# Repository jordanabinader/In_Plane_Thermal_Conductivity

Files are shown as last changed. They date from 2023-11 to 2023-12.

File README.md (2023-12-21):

# In-Plane Thermal Conductivity Project

## Table of Contents
- [In-Plane Thermal Conductivity Project](#in-plane-thermal-conductivity-project)
  - [Table of Contents](#table-of-contents)
  - [Description](#description)
  - [Project Structure](#project-structure)
  - [Using the Repository](#using-the-repository)
    - [Installation](#installation)
    - [Running the program](#running-the-program)
    - [Exiting the program](#exiting-the-program)
  - [Database Schema](#database-schema)
  - [TC08 Note](#tc08-note)

## Description
This project integrates various components such as server, database, web application, controls, and computations for in-plane thermal conductivity analysis. It utilizes a robust Node.js server and a responsive front-end built with Next.js alongside several python scripts communicating with the hardware.

## Project Structure
- **Client**: Implements the user interface using Next.js and manages HTTP requests with axios.
- **Server**: A Node.js server employing Express.js for HTTP requests and connecting to an SQLite3 database, with database manipulation facilitated by Knex.
- **Control**: A collection of python scripts dedicated to recording the data from the thermocouples, controlling the heaters, and calculating the thermal conductivity
  - *Thermal Control*
    - Pico_Talker.py: Setting the duty cycle of the heaters based on the control mode set by the user in the website.
  - *Thermocouple*
    - writeFromDAQ.py: Recieves the data from the TC-08 DAQ and writes the temperatures to the temperature table in the database
    - graphLive.py: Plots the live temperature data along side calculated sin fit for active tests.
    - graphFull.py: Similar functionality to graphLive.py but for looking at the data of previous tests. 

## Using the Repository

### Installation

1. Update and upgrade ubuntu packages
  ```
  sudo apt update && sudo apt upgrade
  ```
2. Install picosdk and drivers for the Pico Logger TC-08. Instructions from: https://www.picotech.com/downloads/linux
  ```
  sudo bash -c 'wget -O- https://labs.picotech.com/Release.gpg.key | gpg --dearmor > /usr/share/keyrings/picotech-archive-keyring.gpg'
  sudo bash -c 'echo "deb [signed-by=/usr/share/keyrings/picotech-archive-keyring.gpg] https://labs.picotech.com/picoscope7/debian/ picoscope main" >/etc/apt/sources.list.d/picoscope7.list'
  sudo apt-get update
  sudo apt-get install libusbtc08
  ```

3. Install Python 3.11
  ```
  sudo apt install python3.11
  ```
4. Install pip
  ```
  sudo apt install python3-pip
  ```

5. Install venv pip package
  ```
  python3.11 -m pip install venv
  ```
6. Install curl
  ```
  sudo apt install curl
  ```
7. Install nvm  
  ```
  curl -o- https://raw.githubusercontent.com/nvm-sh/nvm/v0.39.6/install.sh | bash
  source ~/.bashrc
  ```
8. Install Node LTS 20.10.0 and specify it as default
  ```
  nvm install 20.10.0
  nvm alias default 20.10.0
  ```

9. **Clone the repository**: <!-- Replace git clone command with one specifying version once its released -->
  ```
  git clone https://github.com/jordanabinader/In_Plane_Thermal_Conductivity.git
  cd In_Plane_Thermal_Conductivity/
  ```
10. **Setup the python virtual environment**
  ```
  python3.11 -m venv iptc_venv
  ```
  
11. **Install node dependencies**:
   - For the client:
       ```
       cd client
       npm install
       cd ../
       ```
   - For the server:
       ```
       cd server
       npm install
       cd ../
       ```
12. **Install python dependencies**
  ```
  source iptc_venv/bin/activate
  python3.11 -m pip install -r requirements.txt
  ```

### Running the program
Your current working directory should be the base folder of the In_Plane_Thermal_Conductivity repository

1. Activate the virtual environment
  ```
  source iptc_venv/bin/activate
  ```
2. Check the serial port
  ```
  ls -l /dev/serial/by-id
  ```
  The raspberry pi pico likely defaults to ttyACM0, but if not change the ttyACM0 in the command below to what this command highlights

3. Start everything up
  ```
  python3.11 Startup.py --serial-port /dev/ttyACM0
  ```

### Exiting the program
1. In the terminal window running Startup.py from the command above, hit `ctrl+c`
  
   - A normal exit will look similar to below
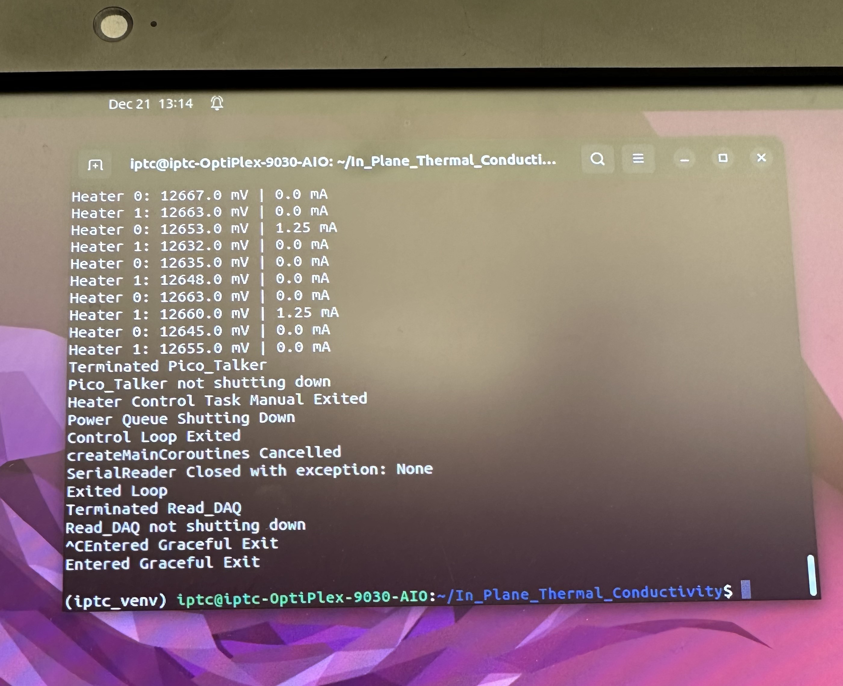
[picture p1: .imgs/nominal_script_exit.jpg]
Image of a nominal exit of the python script

   - If you see more than 3 or 4 print statments in a row that say `{SOMETHING} not shutting down`  the heater control board should be unplugged from and the computer restarted as this means that something went wrong in the shutdown process and the heaters can cause damage if left running while powered

It is also worthwhile to check the terminal output after ending a test to ensure that the heaters get turned off the the thermocouple DAQ gets deactivated properly. The terminal output at the end of a test should look something like the image below. Similar to the what happens when the whole system gets shutdown: If you see more than 3 or 4 print statments in a row that say `{SOMETHING} not shutting down`  the heater control board should be unplugged from and the computer restarted as this means that something went wrong in the shutdown process and the heaters can cause damage if left running while powered. 
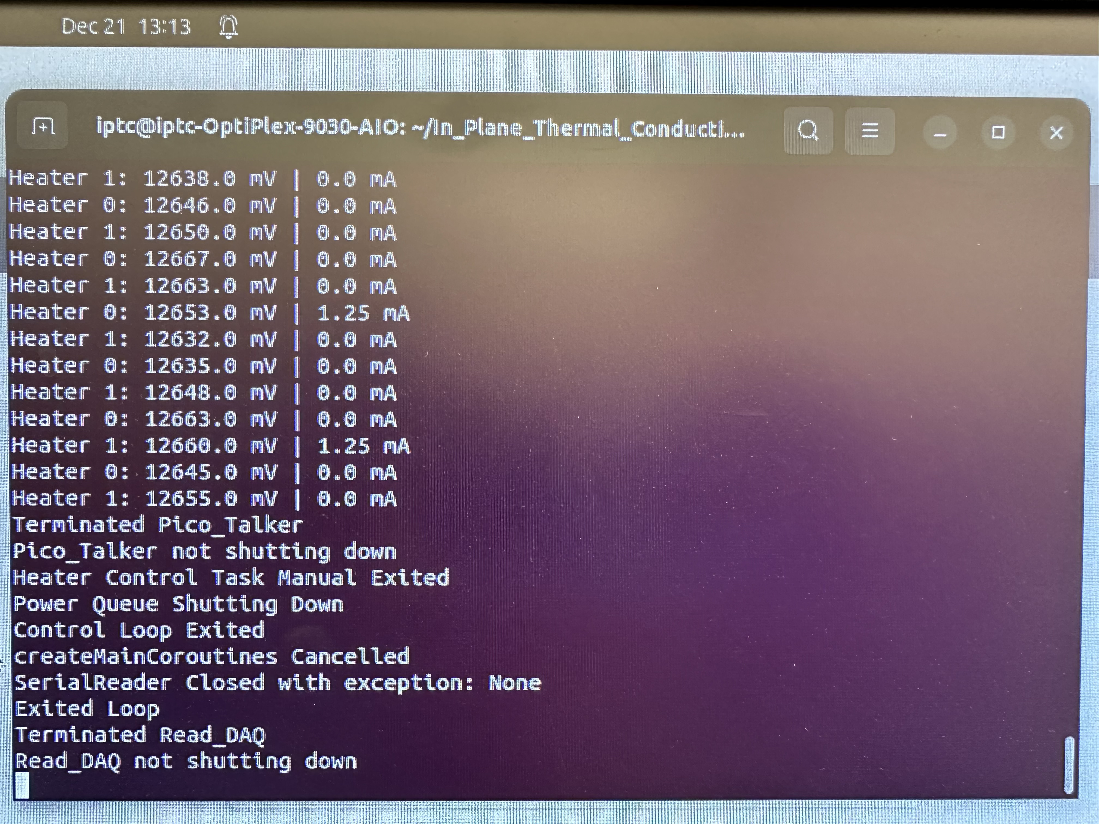
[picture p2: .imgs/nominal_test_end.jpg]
Image of the terminal output when a test is ended properly


## Database Schema
The application uses the following SQLite3 database schemas:

- **Test Settings Table** (`testSettingTableName`):
  - `controlMode`: Float
  - `frequency`: Float
  - `amplitude`: Float
  - `datetime`: DateTime

- **Power Table** (`powerTableName`):
  - `heaterNum`: Float
  - `mV`: Float
  - `mA`: Float
  - `dutyCycle`: Float
  - `datetime`: DateTime

- **Temperature Table** (`temperatureTableName`):
  - `datetime`: DateTime (Default to current time)
  - `relTime`: Float
  - `temp1` to `temp8`: Float (temperature readings for 8 different points)

## TC08 Note
For use with TC-08, you may have to modify library.py of picosdk so it can manually find the installed library

ex. "/Library/Frameworks/Python.framework/Versions/3.12/lib/python3.12/site-packages/picosdk/library.py"

Edit the first line after def _load(self):

library_path = find_library(self.name) ->
library_path = '/Library/Frameworks/PicoSDK.framework/Libraries/libusbtc08/libusbtc08.dylib' For running on Charlie's Macbook Pro

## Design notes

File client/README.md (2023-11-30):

<<<<<<< HEAD
# Capstone_NEU_inPLane_ThermalCond_Web_App
Web App for Capstone project senior year Mechanical Engineering, Northeastern University
=======
This is a [Next.js](https://nextjs.org/) project bootstrapped with [`create-next-app`](https://github.com/vercel/next.js/tree/canary/packages/create-next-app).

## Getting Started

NOTE: For use with TC-08, you will likely have to modify library.py of picosdk.

ex. "/Library/Frameworks/Python.framework/Versions/3.12/lib/python3.12/site-packages/picosdk/library.py"

Edit the first line after def _load(self):

library_path = find_library(self.name) ->
library_path = '/Library/Frameworks/PicoSDK.framework/Libraries/libusbtc08/libusbtc08.dylib' For running on Charlie's Macbook Pro

First, run the development server:

```bash
npm run dev
# or
yarn dev
# or
pnpm dev
# or
bun dev
```

Open [http://localhost:3000](http://localhost:3000) with your browser to see the result.

You can start editing the page by modifying `app/page.js`. The page auto-updates as you edit the file.

This project uses [`next/font`](https://nextjs.org/docs/basic-features/font-optimization) to automatically optimize and load Inter, a custom Google Font.

## Learn More

To learn more about Next.js, take a look at the following resources:

- [Next.js Documentation](https://nextjs.org/docs) - learn about Next.js features and API.
- [Learn Next.js](https://nextjs.org/learn) - an interactive Next.js tutorial.

You can check out [the Next.js GitHub repository](https://github.com/vercel/next.js/) - your feedback and contributions are welcome!

## Deploy on Vercel

The easiest way to deploy your Next.js app is to use the [Vercel Platform](https://vercel.com/new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) from the creators of Next.js.

Check out our [Next.js deployment documentation](https://nextjs.org/docs/deployment) for more details.
>>>>>>> master

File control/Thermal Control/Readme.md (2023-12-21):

# Thermal Control
This folder contains the code necessary to control the heaters connected to the In-Plane Thermal Conductivity (IPTC) Power Distribution and Control PCB that integrates with the larger Web App

## Getting Started
Instructions for how to get started using the power distribution and control PCB and heater control software
### Pico_Talker
Pico_Talker.py is the python script that controls the power output of the heaters.

#### Instructions

1. Install Python. This code was tested to run on Python 3.11.6 and Python 3.11.5
1. Install required packages with: `pip install -r requirements.txt`
1. Run the script with `python Pico_Talker.py {ARGUMENTS}` with the desired arguments. See the arguments section below. 

#### Arguments

For instructions on how to use optional arguments [see this documentation from python](https://docs.python.org/3/howto/argparse.html#introducing-optional-arguments).

Example: `python Pico_Talker.py --port COM4 --baud 115200 --database storage.db`

**--port:** Optional
- Serial Port the IPTC Power Distribution and Control PCB is connected to
- If no port is passed, it uses the Serial_Helper.terminalChooseSerialDevice() to get user input on which port to use

**--baud:** Optional. Default = 115200
- Baud rate that the IPTC Power Distribution and Control PCB is communicating at.
- Shouldn't be changed unless you have made changes to the arduino code

**--database:** Optional. Default "your_database.db"
- The relative path to the database relative to the current working directory of this python script (where the script was started from), or the absolute path on the computer

### IPTC Power Distribution and Control PCB and Arduino Code
This PCB was designed after initial assemblies on protoboards had hazards in the form of insufficient ampacity of the wires use. This PCB also greatly simplified the assembly and reduced the risk of shorts. To make your own, the suggested manufacturer is JLCPCB as that is what the design rules are for and where this project ordered from. To order the exact same thing, upload the [IPTC Power Distribution and Control Fabrication Output zip file](IPTC%20PCB/IPTC%20Power%20Distribution%20and%20Control%20Fabrication%20Output.zip) to JLCPCB. Our order specifications were as follows:
- 2 Layer Board
- 1.6mm thickness
- 1 oz outer copper weight
- HASL (with lead) 

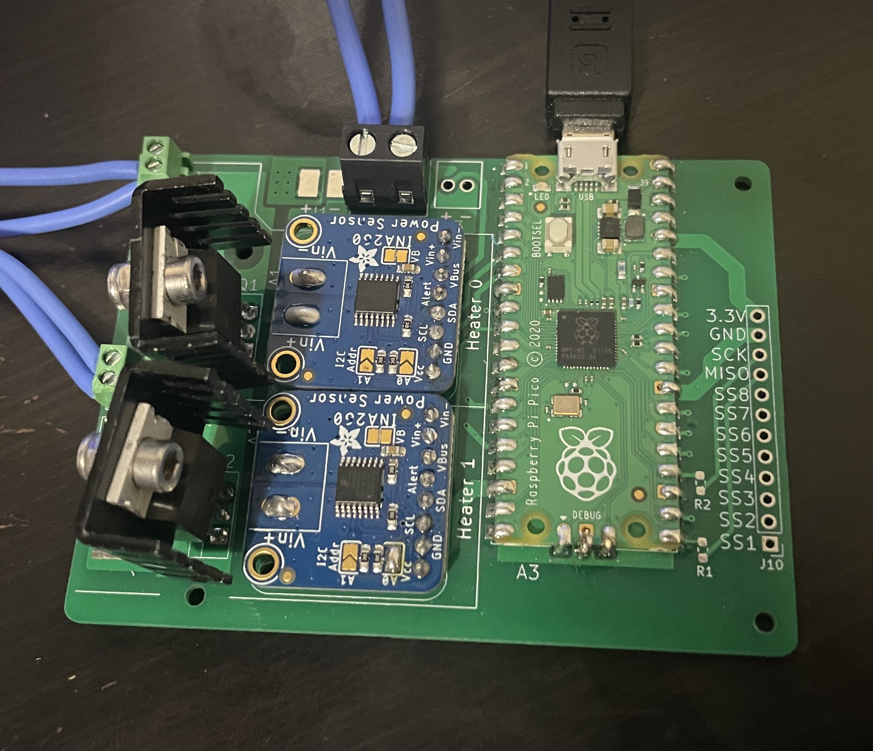
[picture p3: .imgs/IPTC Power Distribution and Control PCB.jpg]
Image of the Assembled IPTC Power Distribution and Control PCB designed by Ben Veghte


The code, in the [IPTC_heater_control](IPTC_heater_control/) folder, can be uploaded directly to the Raspberry Pi Pico on the PCB. Although the PCB has pins broken out for SPI, intended for MAX31855KASA breakout boards, the arduino code and Pico_Talker.py in the current state does not support the use of these pins. If you wish to add this functionality, make the changes necessary and submit a pull-request to the repository. In order to make the addition as seamless as possible, follow the [Serial Communication Pattern](Serial%20Communication%20Pattern.md).

In order to upload the code to the PCB, you need to use the Arduino Mbed OS RP2040 Boards from the Boards Manager in the Arduino IDE and [install the Adafruit INA-260 library](https://learn.adafruit.com/adafruit-ina260-current-voltage-power-sensor-breakout/arduino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)

## Web Interface

Although this script has a couple endpoints, it isn't a webpage that is human readable, the endpoints are just for the primary website to send put requests to to tell Pico_Talker.py to update internal states, such as the current test settings and if the test has ended. Do not send HTTP requests to these endpoints unless you know what your are doing because it could have unintended side effects.

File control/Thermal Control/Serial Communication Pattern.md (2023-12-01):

# Standard Format

| **Section Name** | Header | Packet Data | Termination |
| --- | --- | ---| ---|
| **Length** (bytes) | 1 | 6 | 1
| **Notes** | Describes what kind of packet to follow | Format here is specific to each header | 0xff
| **Options** | <ul><li>Heater 0 Duty Cycle Change (0x01)</li><li>Heater 1 Duty Cycle Change(0x02)</li><li>Dual Heater Duty Cycle Change (0x03)</li><li>Heater 1 INA260 Data (0x11)</li><li>Heater 2 INA260 Data (0x12)</li><li>Heater not found Error (0x21)</ul> | |

## Heater Duty Cycle Change
This applies to both Heater 0 and Heater 1 as they follow the same format 

| **Duty Cycle Change** | Header | Duty Cycle | NULL | Termination
| --- | --- | ---| ---| ---|
| **Length** (bytes) | 1 | 3 | 3| 1
| **Content** | <ul><li>0x01: Heater 0</li><li>0x02: Heater 1</li></ul> | See notes | 0x0 | 0xff
| **Notes** |  | Duty cycle as a int(percent*1000) this makes parsing the number much easier and precision will not really take a hit because it goes to 3 decimal places. Example: Desired Duty Cycle: 25.32%, Transmitted number: 2532 | 

## Dual Heater Duty Cycle Change
This applies duty cycle change to both Heater 0 and Heater 1 as they follow the same format 

| **Duty Cycle Change** | Header | Heater 0 Duty Cycle | Heater 1 Duty Cycle | Termination
| --- | --- | ---| ---| ---|
| **Length** (bytes) | 1 | 3 | 3| 1
| **Content** | 0x03 | See notes | See notes | 0xff
| **Notes** |  | Duty cycle as a int(percent*1000) this makes parsing the number much easier and precision will not really take a hit because it goes to 3 decimal places. Example: Desired Duty Cycle: 25.32%, Transmitted number: 25320  | 

## Heater Not Found Error
| **Heater Not Found Error** | Header | Heater not found | NULL | Termination |
| --- | --- | ---| ---| ---|
| **Length** (bytes) | 1 | 1 | 5| 1| 
| **Content** | 0x21 | <ul><li>0x1 Heater 0</li><li> 0x2: Heater 1</li><li>0x3: Both Heaters</li></ul> | 0x0 | 0xff
| **Notes** |  |  | 

## INA260 Current and Voltage Data
This applies to both Heater 0 and Heater 1 as they follow the same format

| **Duty Cycle Change** | Header | Voltage | Current | Termination
| --- | --- | ---| ---| ---|
| **Length** (bytes) | 1 | 3 | 3 | 1 |
| **Content** | <ul><li>0x11: Heater 0</li><li>0x12: Heater 1</li></ul> | See notes | See Notes | 
| **Notes** |  | Value as a int((mA or mV)*100) this makes parsing the number much easier and precision will not really take a hit because at two decimal places. Example: Measured Voltage: 18000.32mV, Transmitted number: 1800032 | |  0xff |

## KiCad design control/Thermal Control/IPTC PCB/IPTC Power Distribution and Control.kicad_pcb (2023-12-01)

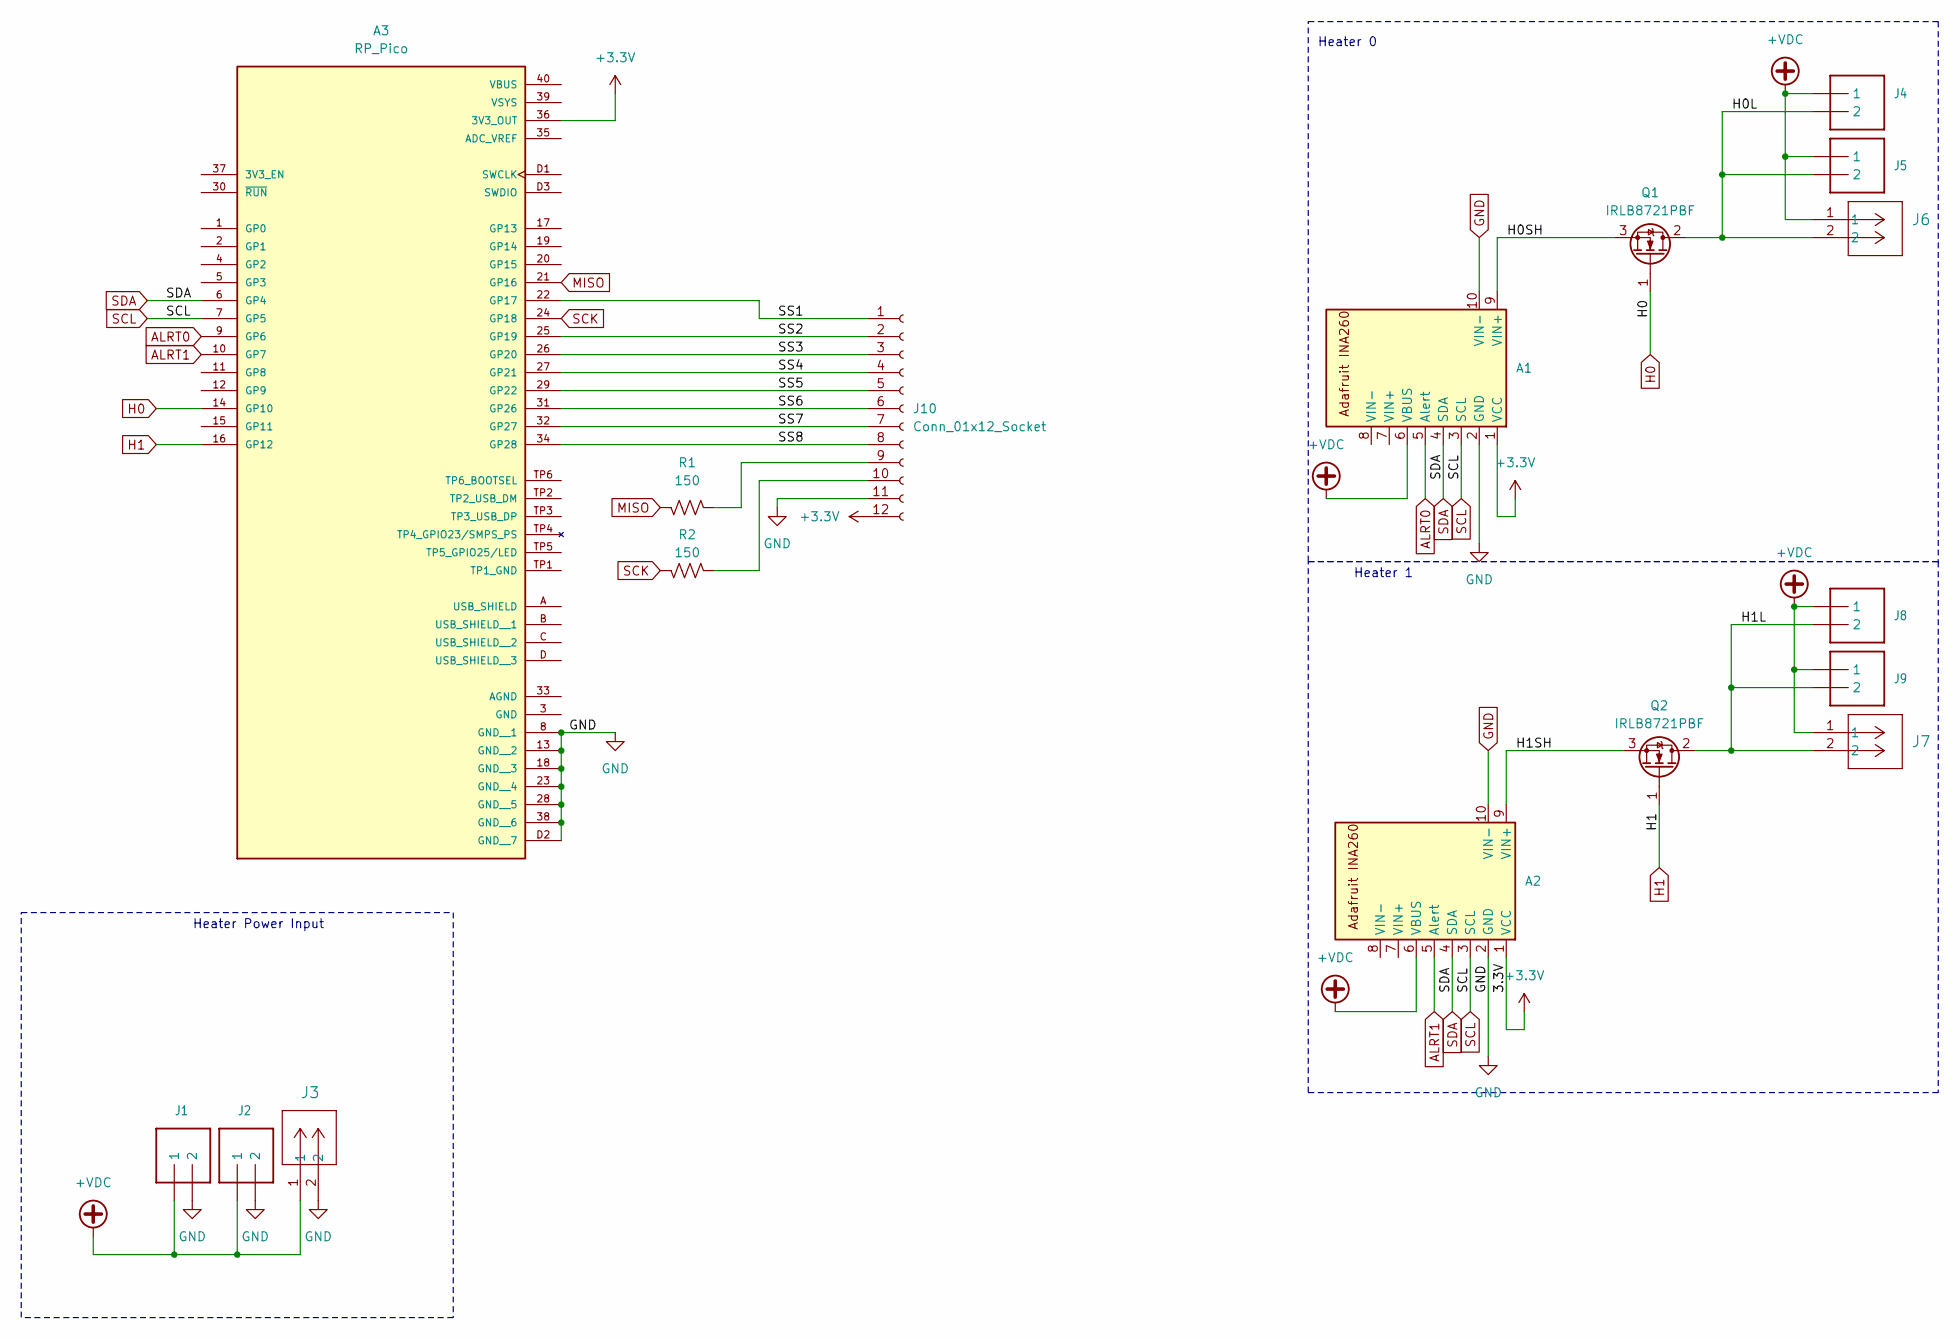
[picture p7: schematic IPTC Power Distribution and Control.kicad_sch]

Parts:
A1, A2: Adafruit_INA260
A3: RP_Pico; PARTREV 1.9
J1, J4, J8: SMD_PAD_1X2_4MMx3MM; SMDPAD_1x2_4MMx3MM
J2, J5, J9: TERMBLOCK_508_1X2
J3, J6, J7: OSTVN02A150; CONN_OSTVN02A150_OST
J10: Conn_01x12_Socket; PinHeader_1x12_P2.54mm_Vertical
Q1, Q2: IRLB8721PBF; TO-220-3_Vertical
R1, R2: 150; R_0603_1608Metric_Pad0.98x0.95mm_HandSolder

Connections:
+3.3V: A1.1 (VCC), A2.1 (VCC), A3.36 (3V3_OUT), J10.12
+VDC: A1.6 (VBUS), A2.6 (VBUS), J1.2 (1), J2.P$3 (1), J3.1, J4.2 (1), J5.P$3 (1), J6.1, J7.1, J8.2 (1), J9.P$3 (1)
/H0L: J4.1 (2), J5.P$4 (2), J6.2, Q1.2 (D)
/H0SH: A1.9 (VIN+), Q1.3 (S)
/H1L: J7.2, J8.1 (2), J9.P$4 (2), Q2.2 (D)
/H1SH: A2.9 (VIN+), Q2.3 (S)
/SS1: A3.22 (GP17), J10.1
/SS2: A3.25 (GP19), J10.2
/SS3: A3.26 (GP20), J10.3
/SS4: A3.27 (GP21), J10.4
/SS5: A3.29 (GP22), J10.5
/SS6: A3.31 (GP26), J10.6
/SS7: A3.32 (GP27), J10.7
/SS8: A3.34 (GP28), J10.8
ALRT0: A1.5 (Alert), A3.9 (GP6)
ALRT1: A2.5 (Alert), A3.10 (GP7)
GND: A1.2 (GND), A1.10 (VIN-), A2.2 (GND), A2.10 (VIN-), A3.8 (GND__1), A3.13 (GND__2), A3.18 (GND__3), A3.23 (GND__4), A3.28 (GND__5), A3.38 (GND__6), A3.D2 (GND__7), J1.1 (2), J2.P$4 (2), J3.2, J10.11
H0: A3.14 (GP10), Q1.1 (G)
H1: A3.16 (GP12), Q2.1 (G)
MISO: A3.21 (GP16), R1.2
unnamed: J10.9, R1.1
unnamed: J10.10, R2.1
SCK: A3.24 (GP18), R2.2
SCL: A1.3 (SCL), A2.3 (SCL), A3.7 (GP5)
SDA: A1.4 (SDA), A2.4 (SDA), A3.6 (GP4)

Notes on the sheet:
Heater 1
Heater Power Input
Heater 0

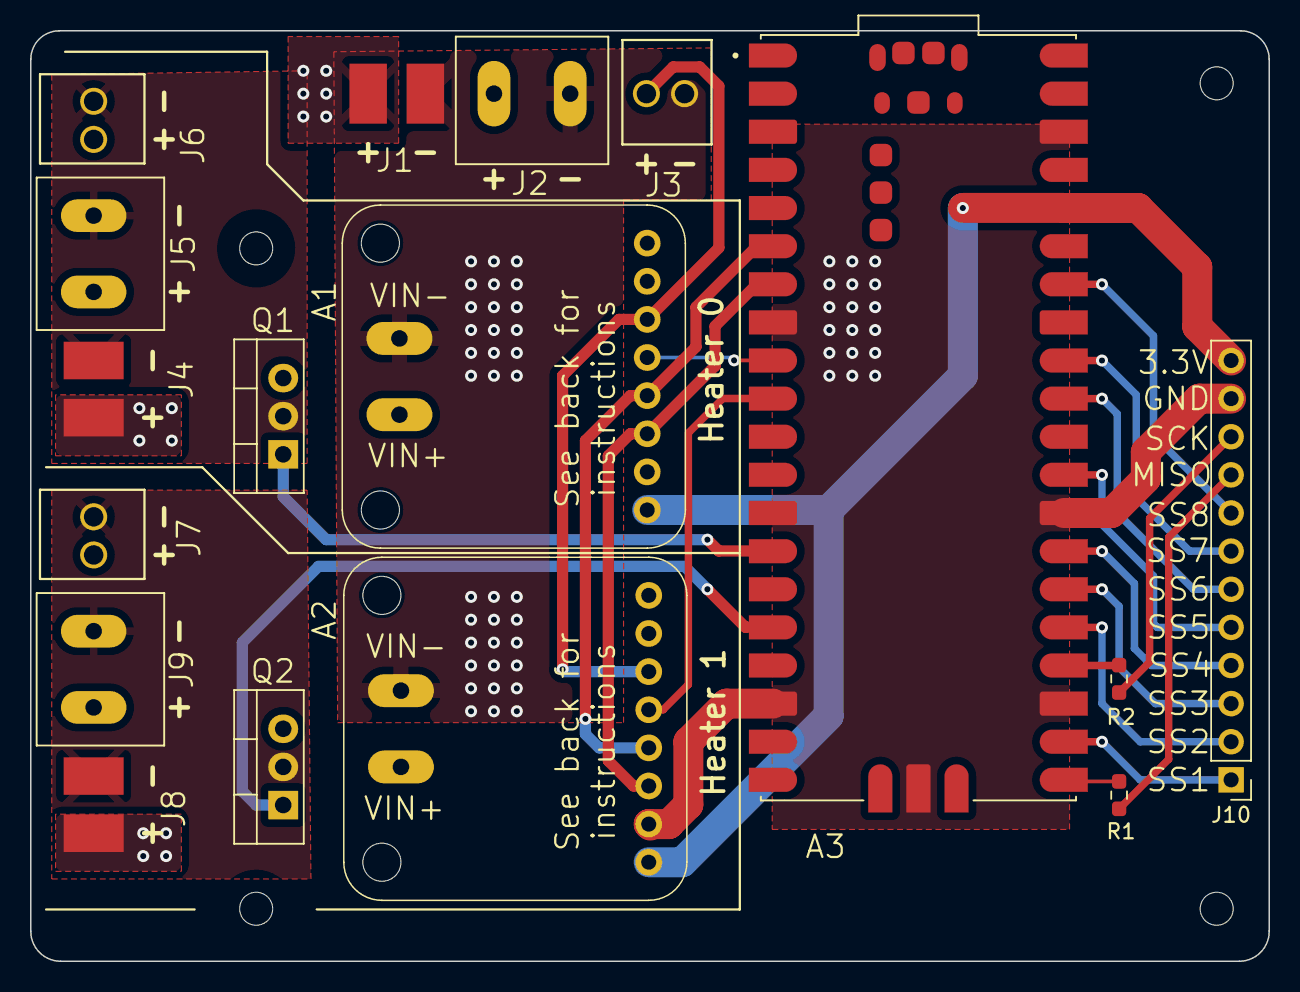
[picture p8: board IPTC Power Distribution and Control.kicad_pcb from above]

Board: 2 copper layers, 82.5 x 62.0 mm, 17 parts (0 on the bottom side), 25 nets.

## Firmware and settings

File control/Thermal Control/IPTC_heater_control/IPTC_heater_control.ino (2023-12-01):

/*
  This code is for the control of the heaters for the In-Plane Thermal Conductivity Measurement Device
  designed by Ben Veghte, Aaron Leach, Rocco Tropea, Jordan Abi-Nader, and Charlie Schatmeyer. 
  This code was written specificaly with Power Distribution and Control PCB in mind with a raspberry pi pico
  however, utilizing other microcontrollers shouldn't require much change to this code.
  */
  //  AUTHOR: Ben Veghte

#include <Adafruit_INA260.h>
#include "RP2040_PWM.h" //Custom, not the library by Khoi Hoang due to it being archived and not tracking latest changes in Arduino Mbed OS RP2040 Boards, changes made using directions found here: https://forum.arduino.cc/t/library-rp2040-pwm-dont-compile/1168488/2 

// Communication Headers, see Serial Communication Pattern.md
#define HEATER_NOT_FOUND_ERROR 0x21
#define HEATER0_DC_HEADER 0x01
#define HEATER1_DC_HEADER 0x02
#define DUAL_DC_HEADER 0x03
#define HEATER0_INA260_HEADER 0x11
#define HEATER1_INA260_HEADER 0x12
#define TERMINATION 0xff


unsigned long timer_start; //variable to time how long operations take

float pwm_freq = 1100; //Hz


#define MSG_LEN 8
byte serial_rec_buf[MSG_LEN]; // For serial data coming in
byte serial_send_buf[MSG_LEN];

#define INA260_READ_PERIOD 2000 //In milliseconds. In order to read the current flowing through the heater, the mosfet needs to be in the on state and hitting the time in the duty cycle when the PWM is high is difficult without getting into the register and haven't figured out how to do that yet
unsigned long last_read = 0;

byte heaters_not_found;

unsigned long ina_mV;
unsigned long ina_mA;
float read_mA;


// Heater 0 Info
#define HEATER0 10 //not the GPxx number but the physical pin number
#define HEATER0_ALERT 9
Adafruit_INA260 heat0 = Adafruit_INA260();
float heat0_duty = 0;
RP2040_PWM* h0_pwm_inst;


// Heater 1 Info
#define HEATER1 12
#define HEATER1_ALERT 10
Adafruit_INA260 heat1 = Adafruit_INA260();
float heat1_duty = 0;
RP2040_PWM* h1_pwm_inst;



void setup() {
  //PWM Initialization
  //Pico can handle 8Hz - 62.5MHz, IRLB8721 maxes out around 4.8MHz due to delay time and rise time, doesn't work using arduino mbed OS RP2040
  pinMode(HEATER0, OUTPUT);
  pinMode(HEATER1, OUTPUT);

  // Serial Initialization
  Serial.begin(115200);
  while(!Serial){ // Wait for serial to be connected
    delay(1);
  }

  //INA Initialization
  //INA260 conversion time (the lenth the sensor averages over) needs to be as close to the period (or multiple periods) of the pwm_freq as possible to get an accuracte average for fault detection
  if (!heat0.begin(0x40)) {
    heaters_not_found = heaters_not_found&0B1;
  }
  if (!heat1.begin(0x41)) { 
    heaters_not_found = heaters_not_found&0B01;
    while(1);
  }
  if(heaters_not_found>0) { //If any heaters aren't found send error and then halt
    serial_send_buf[0] = HEATER_NOT_FOUND_ERROR;
    serial_send_buf[1] = heaters_not_found;
    serial_send_buf[MSG_LEN-1] = TERMINATION;
    Serial.write(serial_send_buf, MSG_LEN);
    memset(serial_send_buf, 0, MSG_LEN); // Empty the array for the next message to send
    while(1);
  }

  //If the code gets to this point, all heaters have been verified to be opertational
  //Set heater conversion time to match up with PWM frequency to ensure that we are getting the expected results
  heat0.setCurrentConversionTime(INA260_TIME_1_1_ms);
  heat0.setVoltageConversionTime(INA260_TIME_1_1_ms);
  heat1.setCurrentConversionTime(INA260_TIME_1_1_ms);
  heat1.setVoltageConversionTime(INA260_TIME_1_1_ms);

  //PWM Initialization
  //Pico can handle 8Hz - 62.5MHz, IRLB8721 maxes out around 4.8MHz due to delay time and rise time, doesn't work using arduino mbed OS RP2040
  h0_pwm_inst = new RP2040_PWM(HEATER0, pwm_freq, heat0_duty);
  h0_pwm_inst->setPWM();
  h1_pwm_inst = new RP2040_PWM(HEATER1, pwm_freq, heat1_duty);
  h1_pwm_inst->setPWM();

}

void loop() {
  //Handle Incoming serial data
  // Pyserial in the handler code is good at handling all sorts of data that the arduino can send
  // however the reverse isn't true, so going to in a standard form
  if (Serial.available() > 0) {
    serial_recv_handler();
  }
  if ((millis()-last_read)>INA260_READ_PERIOD) {
    last_read = millis();
    //Heater 0
    ina_mV = (unsigned long) heat0.readBusVoltage()*100;
    read_mA = heat0.readCurrent();
    ina_mA = (unsigned long) (read_mA <0 ) ? 0 : read_mA*100; //If current is negative, send 0, the negative current is really only sent when there is no current flowing and is an indicator of noise, and its so small we dont care
    serial_send_buf[0] = HEATER0_INA260_HEADER;
    serial_send_buf[1] = byte((ina_mV>>16));
    serial_send_buf[2] = byte((ina_mV>>8) );
    serial_send_buf[3] = byte(ina_mV );
    serial_send_buf[4] = byte(ina_mA>>16);
    serial_send_buf[5] = byte((ina_mA>>8) );
    serial_send_buf[6] = byte(ina_mA );
    serial_send_buf[MSG_LEN-1] = TERMINATION;
    Serial.write(serial_send_buf, MSG_LEN);
    
    //Heater 1
    ina_mV = (unsigned long) heat1.readBusVoltage()*100;
    read_mA = heat1.readCurrent();
    ina_mA = (unsigned long) (read_mA <0 ) ? 0 : read_mA*100;
    serial_send_buf[0] = HEATER1_INA260_HEADER;
    serial_send_buf[1] = byte((ina_mV>>16));
    serial_send_buf[2] = byte((ina_mV>>8) );
    serial_send_buf[3] = byte(ina_mV );
    serial_send_buf[4] = byte(ina_mA>>16);
    serial_send_buf[5] = byte((ina_mA>>8) );
    serial_send_buf[6] = byte(ina_mA );
    serial_send_buf[MSG_LEN-1] = TERMINATION;
    Serial.write(serial_send_buf, MSG_LEN);
  }

}

void serial_recv_handler() {
  Serial.readBytes(serial_rec_buf, MSG_LEN); //Reads MSG_LEN bytes sent by computer following format in Serial Communication Pattern.md
  // Serial.println("Received msg");
  switch (serial_rec_buf[0]) {
    case HEATER0_DC_HEADER: // Heater 0 Duty Cycle Change
      heat0_duty = float((((serial_rec_buf[1]<<8)|serial_rec_buf[2])<<8)|serial_rec_buf[3])*0.001;  
      h0_pwm_inst->setPWM(HEATER0, pwm_freq, heat0_duty);
      // Serial.print("Heater 0 Duty Cycle change to ");
      // Serial.println(heat0_duty);
      break;
    case HEATER1_DC_HEADER: //Heater 1 Duty Cycle Change
      heat1_duty = float((((serial_rec_buf[1]<<8)|serial_rec_buf[2])<<8)|serial_rec_buf[3])*0.001; 
      h1_pwm_inst->setPWM(HEATER1, pwm_freq, heat1_duty);
      // Serial.print("Heater 1 Duty Cycle change to ");
      // Serial.println(heat1_duty);
      break;
    case DUAL_DC_HEADER:
      heat0_duty = float((((serial_rec_buf[1]<<8)|serial_rec_buf[2])<<8)|serial_rec_buf[3])*0.001; 
      h0_pwm_inst->setPWM(HEATER0, pwm_freq, heat0_duty);
      // Serial.print("Heater 0 Duty Cycle change to ");
      // Serial.println(heat0_duty, 3);
      heat1_duty = float((((serial_rec_buf[4]<<8)|serial_rec_buf[5])<<8)|serial_rec_buf[6])*0.001; 
      h1_pwm_inst->setPWM(HEATER1, pwm_freq, heat1_duty);
      // Serial.print("Heater 1 Duty Cycle change to ");
      // Serial.println(heat1_duty, 3);


  }

}

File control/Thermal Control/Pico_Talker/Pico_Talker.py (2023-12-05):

import Serial_Helper
import argparse
import re
import asyncio
import serial_asyncio #Tutorial used: https://tinkering.xyz/async-serial/
import aiosqlite
from collections.abc import Iterable
import time
from datetime import datetime
import math
from functools import partial
from aiohttp import web
import aiohttp_cors
import signal
import os
from typing import Tuple, List

#########################################################################
#FILE VARIABLES

#Variables for use inititializing databases
TEST_DIRECTORY_TABLE_NAME = "test_directory"
POWER_TABLE_NAME_BASE = "power_table" #Base strings for the test specific tables that the test name gets appended to with testNameTableFormatter
TEST_SETTING_TABLE_NAME_BASE = "test_settings" #Base strings for the test specific tables that the test name gets appended to with testNameTableFormatter

TEST_SETTING_TABLE_NAME = "" #Filled in by connectDatabase
POWER_TABLE_NAME = "" #Filled in by connectDatabase
POWER_INITIALIZATION_QUERY = "" #Filled in by connectDatabase
TEST_SETTING_INITIALIZATION_QUERY = "" #Filled in by connectDatabase

#Serial Communication Constants (see Serial Communication Pattern.md)
MSG_LEN = 8
HEATER_NOT_FOUND_ERROR = 0x21
DUTY_CYCLE_CHANGE_HEADER = (0x01, 0x02, 0x03) # Heater 1, Heater 2, Both Heaters
INA260_DATA_HEADER = (0x11, 0x12)
TERMINATION = 0xff

#For regex searching
ACCEPTABLE_MSG_HEADERS = bytes() #Flatten acceptable headers, for use in parsing serial messages
for h in [DUTY_CYCLE_CHANGE_HEADER, INA260_DATA_HEADER, HEATER_NOT_FOUND_ERROR]:
    if isinstance(h, Iterable):
        for i in h:
            ACCEPTABLE_MSG_HEADERS += i.to_bytes()
    else:
        ACCEPTABLE_MSG_HEADERS += h.to_bytes()

#Webhook Endpoints
TEST_SETTING_ENDPOINT = "/test-setting-update"
END_TEST_ENDPOINT = "/test-end"
SCRIPT_ALIVE_ENDPOINT = "/script-alive"


class SerialComm(asyncio.Protocol):
    def __init__(self, power_queue:asyncio.Queue, test_setting_queue:asyncio.Queue, db:aiosqlite.Connection, network_port:int = 3001, heater_scalar:Tuple[float, float] = (1,1), heater_resitance: Tuple[float, float] = (0.05, 0.05), supply_voltage:float = 12):
        """Class for managing serial communicaiton with the raspberry pi pico power distribution and control PCB
        Source for this method of using functools.partial: https://tinkering.xyz/async-serial/#the-rest
        Args:
            power_queue (asyncio.Queue): Queue instance that stores the data from the INA260 voltage and current monitoring
            test_setting_queue (asyncio.Queue): Queue instance for updating test settings
            db (aiosqlite.Connection): The database storing all the info for the test setup
            network_port (int, optional): Network port for the webserver to listen to for test setting and test end requests. Defaults to 3001.
            heater_scalar (Tuple[float, float], optional): (heater 0, heater 1),heaters are going to have different thermal masses as bottom heater has more to heat up so having a scalar would allow both blocks to heat similarly. Defaults to (0,0).
            heater_resitance (Tuple[float, float], optional): Ohms, (heater 0, heater 1), measured value, as different heaters are going to have different resistances. Defaults to (0.05, 0.05).
            supply_voltage (float, optional): Volts, The supply voltage that drives the heaters. Defaults to 12.
        """

        super().__init__()
        self.transport = None
        self.db = db
        #Queues
        self.test_setting_queue = test_setting_queue
        self.power_queue = power_queue
        
        #Test Setup info
        self.duty_cycle = [0, 0] #% duty cycle of each heater, useful for ensuring that the power output lines up properly
        self.HEATER_RESISTANCE = heater_resitance
        self.HEATER_SCALAR = heater_scalar
        self.SUPPLY_VOLTAGE = supply_voltage
        self.HEATERS = (0, 1) # Mapping for heater numbers
        self.DUTY_CYCLE_UPDATE_PERIOD = 0.1 # Seconds

        #Webpage network info
        self.port = network_port

        #Test Setting Information
        self.CONTROL_OPTIONS = {
            "manual": self.heaterManual,  # Parse db table amplitude column as duty cycle in percent to send to serial device
            "power": self.heaterPower     # Sine wave of power, Amplitude column in watts, frequency column in rad/s
            #, "Temperature": self.heaterTemp # Possible addtion of temperature control in the future, needs a PID loop to ensure temperatures are accurate. Amplitude is amplitude of temp sine, frequency in rad/s, would need to add a new column for the vertical offset.
        }
        self.control_mode = "manual" # Default Setting so that the test starts off with all the heaters off
        self.frequency = 0 #Rad/s
        self.amplitude = 0 # units depend on control mode, see self.CONTROL_OPTIONS
        self.start_time = time.time()
        self.connected = False

    #########################################################################
    #Serial Communication
    def connection_made(self, transport:serial_asyncio.SerialTransport):
        """Gets called when serial is connected, inherited function

        Args:
            transport (serial_asyncio.SerialTransport): input gets passed by erial_asyncio.create_serial_connection()
        """
        self.connected = True
        self.transport = transport
        self.pat = b'['+ACCEPTABLE_MSG_HEADERS+b'].{'+str(MSG_LEN-2).encode()+b'}'+TERMINATION.to_bytes()
        self.read_buf = bytes()
        self.bytes_recv = 0
        self.msg = bytearray(MSG_LEN)
        print("SerialReader Connection Created")
        webserver_task = asyncio.ensure_future(self.initWebserver())
        webserver_task.set_name("Webserver-Task")
        control_loop_task = asyncio.ensure_future(self.controlLoop())
        control_loop_task.set_name("Control-Loop-Task")

        self.heater_control_task = asyncio.ensure_future(self.stall()) #The Function that is inside this task gets controlled by self.controlLoop
        self.heater_control_task.set_name("Heater-Control-Task")

    def connection_lost(self, exc:Exception):
        """Gets called when serial is disconnected/lost, inherited function

        Args:
            exc (Exception): Thrown exception
        """
        self.connected = False
        print(f"SerialReader Closed with exception: {exc}")
    
    async def parseMsg(self, msg:bytes):
        """Parse a message sent by the raspberry pi pico and add it the proper queue to get put into the database

        Args:
            msg (bytes): bytes object of length MSG_LEN that matched the self.pat
        """
        if msg[0] == INA260_DATA_HEADER[0]: #INA260 Data Heater 0
            mV = ((((msg[1]<<8)+msg[2])<<8)+msg[3])/100
            mA = ((((msg[4]<<8)+msg[5])<<8)+msg[6])/100
            print(f"Heater 0: {mV} mV | {mA} mA")
            await self.power_queue.put([0, mV, mA, self.duty_cycle[0], datetime.now().__str__()])
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

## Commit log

2023-12-01 Add Thermal Control Files
    Thermal Control files copied over from legacy repo "Capstone_NEU_inPLane_ThermalCond" to centralize all the files to run the script.
    [IPTC Power Distribution and Control-B_Cu.gbl, IPTC Power Distribution and Control-B_Mask.gbs, IPTC Power Distribution and Control-B_Paste.gbp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]
2023-12-02 removing print statements
2023-12-02 control_modes to lower case to match db schema
2023-12-02 Fix Hz to rad/s conversion
    [Pico_Talker.py]
2023-12-04 Fiexd table filtering
2023-12-04 Switch test-start endpoint to Startup.py
2023-12-04 Add terminate print output
2023-12-05 Switch manual control from duty cycle to power output
    Previously manual control interpreted the amplitude column of the database as a duty cycle to send to both heaters, however that could be confusing so this switches manual control to interpreting the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
2023-12-05 fix hz to radian typo with **
    [Pico_Talker.py]
2023-12-06 flip order cut/fit data
2023-12-06 Don't fit temperature sine with small num points
2023-12-06 Shader stops at current time
    fitted_range_shader now ends at the current time instead of extending to the edge of the graph
2023-12-06 graphLive now uses port 8125
    switch graphLive port to new port so that graphLive and graphFull can run simultaneously
